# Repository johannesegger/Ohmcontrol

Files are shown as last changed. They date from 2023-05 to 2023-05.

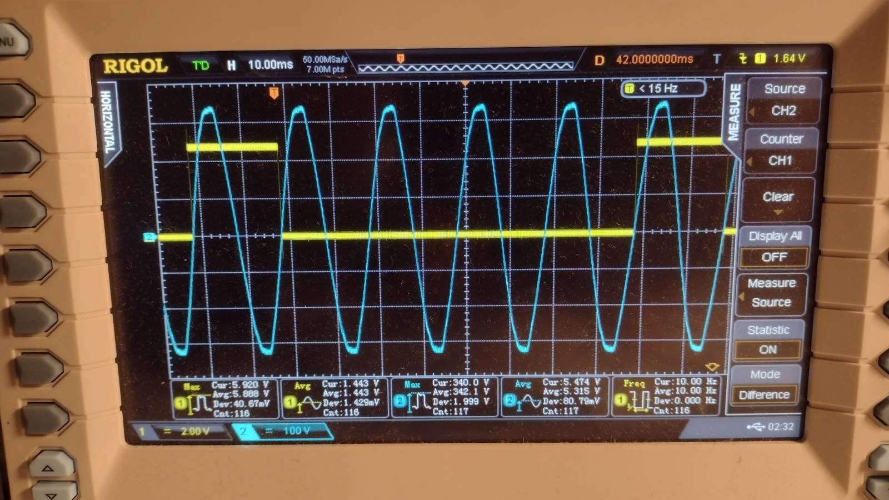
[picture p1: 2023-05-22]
doc/signal-2022-09-05-222630_002.jpeg

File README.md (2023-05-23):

# Ohmcontrol

DIY replacement for Fronius Ohmpilot.

> Warning: Don't do this on your own if you're a software-only guy like me. Get professional help from someone who understands electronic shizzle (thank you, [Stefan, my dear brother](https://github.com/bananenbaer)).

## Hardware

* Raspberry Pi
  * Tested with a RPi 3 Model B+, but it should work with any model that can run a Python script.
* Arduino Nano
* 3 x SSR Relay + Radiator
  * It should be activated with 3V3 (*load voltage*) as this is what RPi gives us.
* 6 x M-F Jumper Breadboard Wire
  * To connect RPI/Arduino with the Relays.
* Status LED
* Resistors

### Setup

* Connect RPi GPIO pins 16 and 26 each to a relay (Control +).
  * Those two relays are either on or off.
* Connect RPi GND pins (any) each to a relay (Control -).
* Connect Arduino digital pin D10 to the third relay (Control +).
  * This relay will simulate PWM by turning it off for some half-waves.
* Connect Arduino GND pin (any) to the third relay (Control -).
* Connect RPi UART TX/RX (GPIO 14/15) pins to Arduino serial pins (RX1/TX0).
* Connect phase to Arduino D2 (use resistors to reduce voltage down to 3.3V)
  * This is necessary to detect zero-crossing of voltage for switching PWM relay state.
  * Zero-cross-detection works best when no other devices use that phase.
* Connect Arduino D3 (R), D5 (G) and D6 (B) to status LED.

```
   Separate phase       Separate phase     |      Separate phase       Separate phase
      from grid          to Ohmpilot       |         from grid          to Ohmpilot
          │                   │            |             │                   │
       ┌──┴───────────────────┴──┐         |          ┌──┴───────────────────┴──┐
       │ Load               Load │         |          │ Load               Load │
2 X    │          Relay          │         |   1 X    │          Relay          │
       │ Control -     Control + │         |          │ Control -     Control + │
       └───┬────────────────┬────┘         |          └───┬────────────────┬────┘
           │                │              |              │                │
        RPi GND    RPi GPIO pin 16/26      |         Arduino GND    Arduino pin D10
```

## Software

### Raspberry Pi

* Flash SD card e.g. using [Raspberry Pi Imager](https://www.raspberrypi.com/software/).
  * Set all necessary settings so that you can connect to your RPi after it starts up.
* Connect to your RPi e.g. using [Visual Studio Code](https://code.visualstudio.com/docs/remote/ssh).
* Run the following commands to clone the repository and install Ohmcontrol as service:
    ```bash
    sudo apt update && sudo apt install -y git
    git clone https://github.com/johannesegger/Ohmcontrol
    cd Ohmcontrol
    ./setup.sh
    ```
* Check logs
    ```bash
    journalctl -u ohmcontrol -r
    ```

### Arduino Nano

* Compile and upload `pwm.ino` to your Arduino.

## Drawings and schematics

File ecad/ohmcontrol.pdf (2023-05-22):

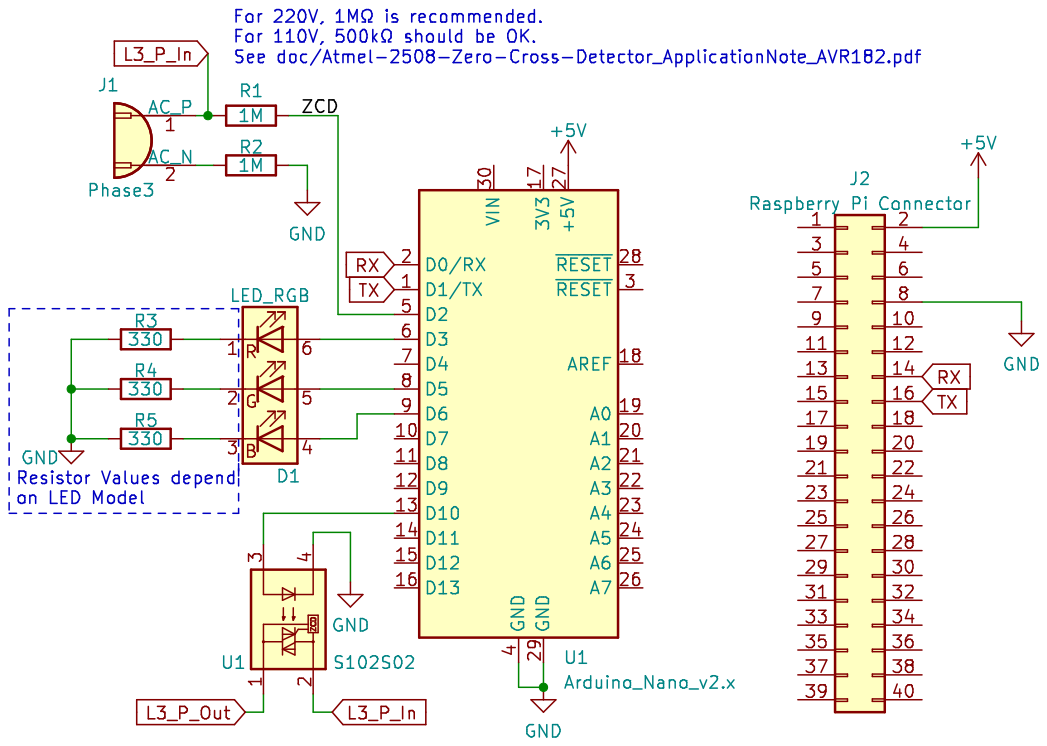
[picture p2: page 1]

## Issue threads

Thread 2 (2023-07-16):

PWM will ignore PV-Load

CGES19, 2023-07-16:
The solution of PWM with full wave control does not bring the desired result. The power is controlled via this PWM, but it does nothing to optimize the self-consumption of the PV power. Each full wave loads the circuit with 100%. I.e. I load with 3000 watts, but the PV system supplies only 2000 watts, then the missing 1000 watts are supplied by the power supplier, which you also have to pay. An optimization only works if every single sine wave of the alternating current is chopped into small parts (PWM).

johannesegger, 2023-07-18:
Thanks for your input.

I guess that depends on your supplier. For me it looks like billing is based on 15 minutes intervals, so what I produce and what I consume is summed up for 15 minutes and the result is what I pay for or what I earn.

Here is my consumption data for May 2023 (I chose May here because I produced a lot and self-consumed a lot):

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

And here is what I paid for (265 kWh in total):

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

Are you sure that your supplier bills based on every sine wave? That would be *a lot* of data. Also someone told me that [switching during a wave](https://en.wikipedia.org/wiki/Phase-fired_controller) is not good because many devices doing so change the form of the sine wave until it's no longer recognizable as a sine wave.

Closed 2023-07-30.

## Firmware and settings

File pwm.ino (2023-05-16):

#include <util/atomic.h>

#define LEDR_PIN   3
#define LEDG_PIN   6
#define LEDB_PIN   5

#define RED    0b011
#define GREEN  0b101
#define BLUE   0b110
#define YELLOW 0b001

#define MAINS_PIN   2
#define RELAY_PIN  10

// after this delay, turn red LED on. TODO: notify rpi about it.
#define ZERO_CROSS_TIMEOUT_MS 3000

#define PWM_NR_WAVES 10

static volatile bool zeroCrossing = false;
static unsigned long lastZeroCross;

void setup()
{
    // MAINS_PIN toggles between 1 and 0 every time the Mains voltage passes 0V.
    // if Mains is <=0, MAINS_PIN will read 0. otherwise 1.
    pinMode(MAINS_PIN, INPUT);

    pinMode(LEDR_PIN, OUTPUT);
    pinMode(LEDG_PIN, OUTPUT);
    pinMode(LEDB_PIN, OUTPUT);

    // initialize Relay to 'off' state
    pinMode(RELAY_PIN, OUTPUT);
    digitalWrite(RELAY_PIN, LOW);

    // configure MAINS_PIN as interrupt source, notifying the main loop that we just crossed zero
    attachInterrupt(digitalPinToInterrupt(MAINS_PIN), [](){zeroCrossing=true;}, CHANGE);

    Serial.begin(115200);

    lastZeroCross = millis();
}

static uint8_t pwm = 0;
static uint8_t waveCnt = 0;


void setLeds(uint8_t bitmask)
{
    // analog == pwm, and this is done because apparently I'm too stupid to calculate resistor values for LEDs...
    // ... and 100/255 ~= 40% duty cycle (inverted) looks like a nice yellow, combined with 100% green
    analogWrite(LEDR_PIN, ((bitmask >> 2) & 1) ? 255 : 100);
    digitalWrite(LEDG_PIN, (bitmask >> 1) & 1);
    digitalWrite(LEDB_PIN, (bitmask >> 0) & 1);
}


void loop()
{
    // TODO detect millis() overflow
    bool isPhasePresent = (millis() - lastZeroCross < ZERO_CROSS_TIMEOUT_MS);
    if (isPhasePresent)
    {
        setLeds(pwm == 0 ? GREEN : YELLOW);
    }
    else
    {
        // phase is not connected or the fuse triggered

        // TODO this does only work when absolutely nothing is coupling into the L/N wires...
        // ... which is then triggering 0-cross detection
        pwm = 0;
        setLeds(RED);
    }

    // Check if controller sent something
    if (Serial.available())
    {
        String cmd = Serial.readStringUntil(' ');
        // supported commands: 'PWM xy'
        if (cmd == "PWM")
        {
            // read value (xy)
            int rpiPwm = Serial.readStringUntil('\n').toInt();
            // sanity check
            if (rpiPwm > 100 || rpiPwm < 0 || (rpiPwm % 10 != 0))
            {
                Serial.print("FAIL: No entiendo '" + String(rpiPwm) + "', must be 0, 10, 20, ... 90 or 100\n");
                return;
            }

            waveCnt = 0; // reset wave counter
            pwm = (uint8_t)rpiPwm; // update internal pwm setting and acknowledge command

            Serial.print("SUCCESS: " + String(rpiPwm) + "%\n");
        }
        else
        {
            Serial.print("FAIL: Unknown Command " + cmd + "\n");
            return;
        }
    }

    // access to 'zeroCrossing' variable needs to be atomic because it's also written inside an interrupt routine
    ATOMIC_BLOCK(ATOMIC_RESTORESTATE) // https://forum.arduino.cc/t/demonstration-atomic-access-and-interrupt-routines/73135/2
    {
        if (zeroCrossing)
        {
            lastZeroCross = millis();
            // reset strobe
            zeroCrossing = false;

            // counting waves until we reach the pwm value, then we switch off for the rest of the period (10 half-waves total)
            if (waveCnt*PWM_NR_WAVES >= pwm)
            {
                digitalWrite(RELAY_PIN, LOW);
            }
            else
            {
                digitalWrite(RELAY_PIN, HIGH);
            }
            if (++waveCnt >= 10)
                waveCnt = 0;
        }
    }
    delayMicroseconds(20);
}

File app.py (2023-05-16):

#!/usr/bin/env python3

import logging
import requests
from threading import Event
import RPi.GPIO as GPIO
import signal
import sys
import pwm
from fn import update_state, state_to_string

if len(sys.argv) < 2:
    sys.exit("Usage: python3 app.py <inverter-host-name>")

host_name = sys.argv[1]

logger = logging.getLogger(__name__)
logger.setLevel(logging.INFO)
formatter = logging.Formatter(fmt="%(asctime)s %(name)s.%(levelname)s: %(message)s", datefmt="%Y-%m-%d %H:%M:%S")
handler = logging.StreamHandler(stream=sys.stdout)
handler.setFormatter(formatter)
logger.addHandler(handler)

on_off_relay_pin_numbers = [26, 16]

GPIO.setmode(GPIO.BCM)
for pin_number in on_off_relay_pin_numbers:
    GPIO.setup(pin_number, GPIO.OUT, initial = GPIO.LOW)

pwm.init(pwm.rpiPort)

quitEvent = Event()

def quit(_signo, _frame):
    quitEvent.set()

signal.signal(signal.SIGINT, quit)
signal.signal(signal.SIGTERM, quit)

state = (0b00, 0.0)

try:
    while not quitEvent.is_set():
        response = requests.get(f'http://{host_name}/solar_api/v1/GetPowerFlowRealtimeData.fcgi')
        watt_to_grid = float(response.json()['Body']['Data']['Site']['P_Grid']) * -1
        new_state = update_state(state, watt_to_grid)
        logger.info(f"Power to grid: {watt_to_grid}W - Current State: {state_to_string(state)} - Desired state: {state_to_string(new_state)}")

        (current_on_off_state, current_pwm_ratio) = state
        (desired_on_off_state, desired_pwm_ratio) = new_state
        for (index, pin_number) in enumerate(on_off_relay_pin_numbers):
            current_state = (current_on_off_state >> index) & 0b1 != 0
            desired_state = (desired_on_off_state >> index) & 0b1 != 0
            if current_state != desired_state:
                logger.info(f"  Set pin #{pin_number} to {desired_state}")
                GPIO.output(pin_number, desired_state)

        if current_pwm_ratio != desired_pwm_ratio:
            logger.info(f"  Set PWM ratio to {desired_pwm_ratio:.0%}")
            pwm_error = pwm.set(int(desired_pwm_ratio * 100))
            if pwm_error:
                logger.error(f"    Error while setting PWM ratio: {pwm_error}")

        state = new_state
        quitEvent.wait(60)
finally:
    GPIO.cleanup()
    pwm.set(0)

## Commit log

2022-08-11 Add sample requests
2022-08-12 Fix calculating desired state
    [app.py]
2022-08-12 Fix handling service interrupts
    [app.py]
2022-08-14 Use GPIO pin numbers compatible with Sense HAT
2023-05-16 Calculate state with two on/off relays and one PWM relay
2023-05-16 Add instructions to flash Arduino
2023-05-17 add ZCD documentation; schematics
    [ohmcontrol.kicad_pcb, ohmcontrol.kicad_sch]
2023-05-23 Fix LED pin number
